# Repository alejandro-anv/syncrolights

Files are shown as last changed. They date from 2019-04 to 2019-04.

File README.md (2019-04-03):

# syncrolights

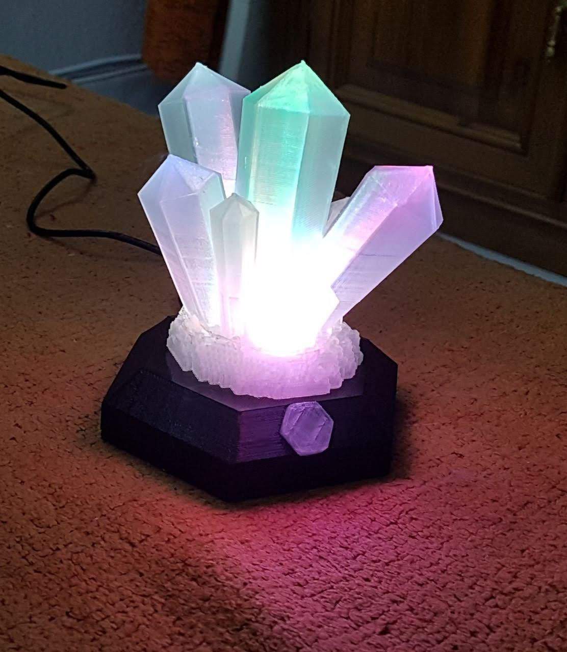
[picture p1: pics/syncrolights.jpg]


This project consists on a system of decorative lights that changes color by pressing a button, but syncronyzed through internet with their "partners". So, when the color of one of them is changed, the others mimics this change.

[YouTube](https://youtu.be/mCSxQj67VzU)

# Synchronization method
For mantaning the syncronization without NAT problems, it is needed to have a central server in "the cloud". For avoiding the need of creating a server there is the alternative of using an existing public service like Telegram. I choosen to use the old IRC protocol. 

The strategy consists on that all the lights that are in the same group will keep connected to the same IRC channel. When one user changed the color, the device will send a "topic" change to the IRC channel. This way the IRC sever will notify the topic change to all the other clients that has joint this channel and then will change the color.

# Plastic parts
The case for this project consists on two parts. One of them is a simulation of crystals that I've found at thingiverse:

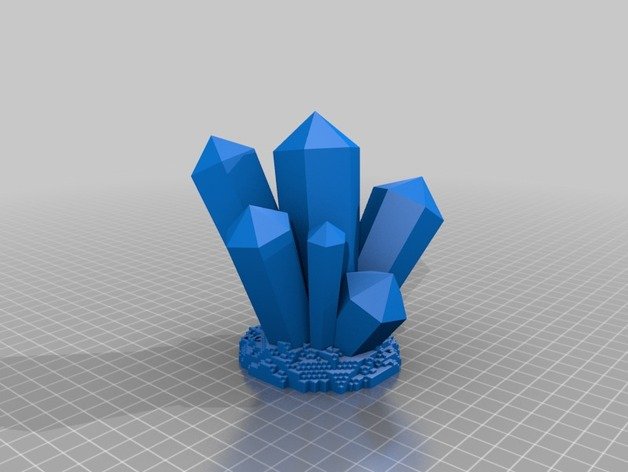
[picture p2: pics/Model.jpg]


(https://www.thingiverse.com/thing:1330791)

This crylsals will be 3D printed with tarnspartent PLA wich will result in a translulcid material and the layers will difuse the light with a prety result.

The base is printed with black PLA. I've uploaded the model to thingiverse

(https://www.thingiverse.com/thing:3537644)

# The electronics
For this function we will use a WEMOS D1 Mini module which consists on an ESP8266 processor with an USB-SRIAL CH340; they are very cehap (about $3). The color lights will be RGB LEDs driven by transistors for allowing to connect various of them without overloading the ESP9266 GPIO aoutputs. The power will be provided driectly from USB using a phone charger connected to the micro-USB port of the board.

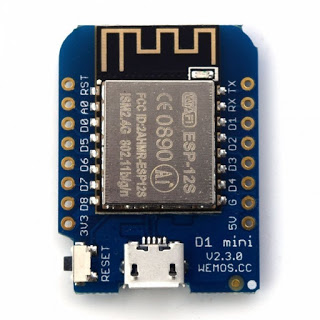
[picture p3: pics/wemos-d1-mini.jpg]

(https://www.aliexpress.com/item/D1-mini-Mini-NodeMcu-4M-bytes-Lua-WIFI-Internet-of-Things-development-board-based-ESP8266-by/32651747570.html)

For choosing the color, wee need a pushbutton. In the prototype I used a common one connected from pin D3 to GND but in the final version I decded to use some more "geek". I've found the TTP223 caacitive modules at 10 for $1,24, then I decided to include one. NOTE: for simulating the active-low effect you must solder the jumper A on the board

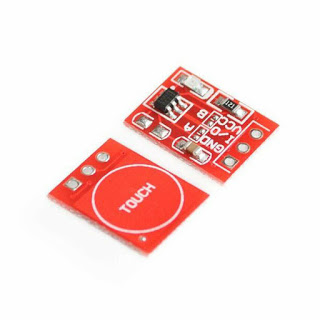
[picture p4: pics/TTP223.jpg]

https://www.ebay.com/itm/10X-TTP223-Touch-Key-Module-Capacitive-Settable-Self-lock-No-lock-Switch-Board/332931518377

Nevertheless, I've used a pushbutton that can be accessed through a small hole in the down side that will be used to enter configuration mode.
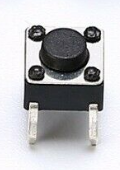
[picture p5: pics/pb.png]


(to be continued)

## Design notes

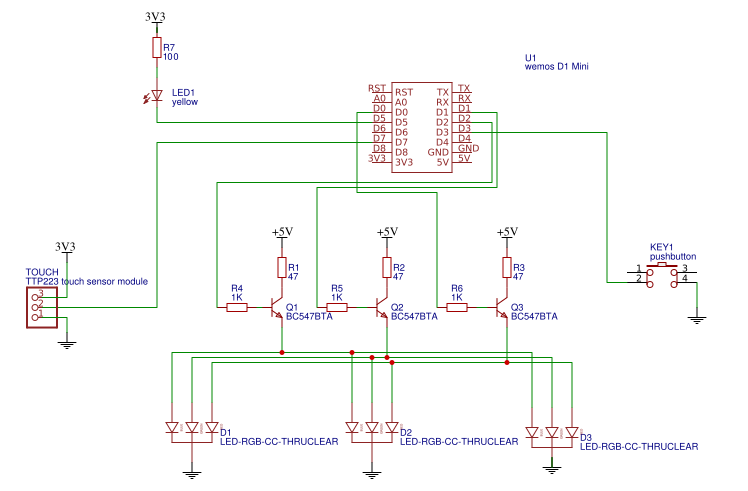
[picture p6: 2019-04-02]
Schematic.png

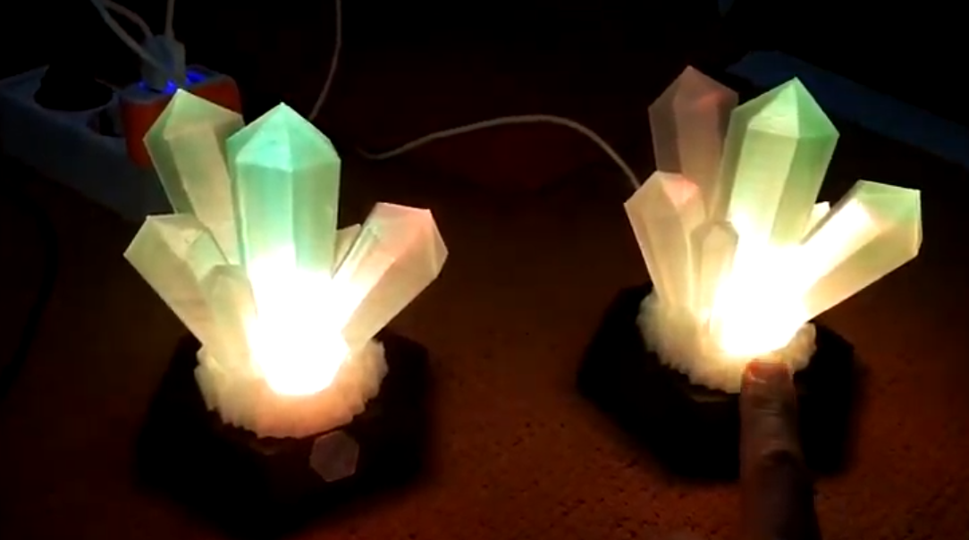
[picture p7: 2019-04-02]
pics/sl2.png

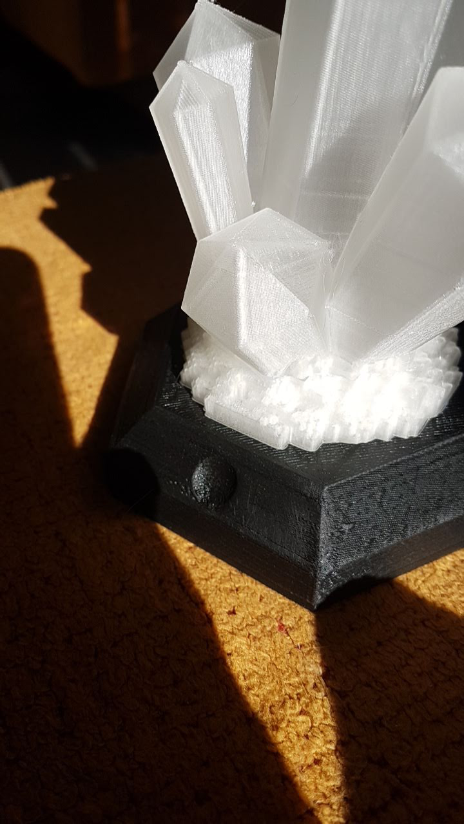
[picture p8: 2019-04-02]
pics/capacitive button.jpg

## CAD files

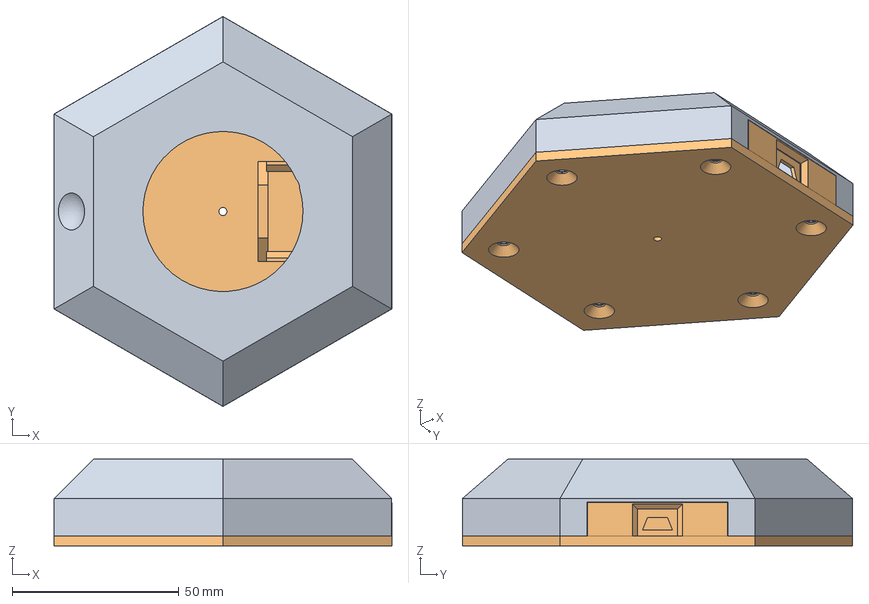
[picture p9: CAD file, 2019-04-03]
3d/sycrolights_base.fcstd
101.4 x 117.0 x 26.0 mm
superior final
inferior final

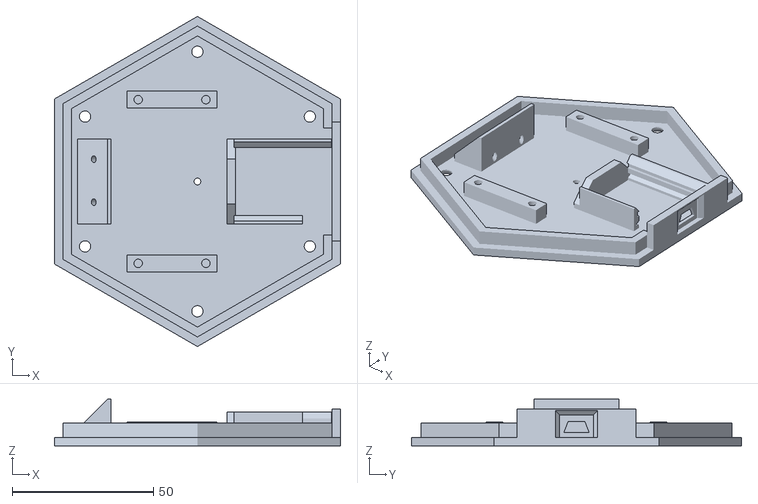
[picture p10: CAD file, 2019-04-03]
3d/down part.stl
101.4 x 117.0 x 16.5

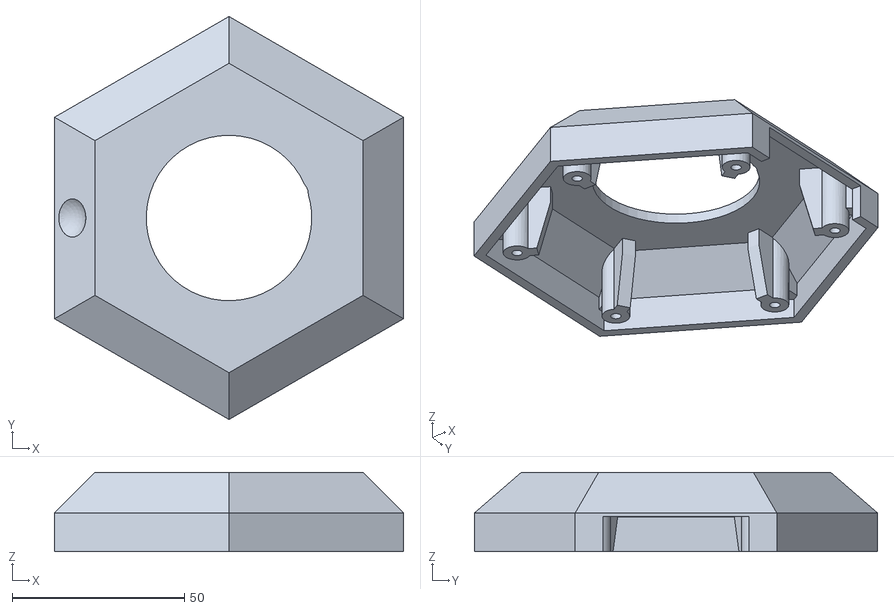
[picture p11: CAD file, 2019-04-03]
3d/up part.stl
101.3 x 116.9 x 23.0

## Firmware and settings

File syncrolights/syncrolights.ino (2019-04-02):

/******************************************************************************
    Copyright (C) 2019 by Alejandro Vargas <alejandro.anv@gmail.com>

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
    You should have received a copy of the GNU General Public License
    along with this program.  If not, see <http://www.gnu.org/licenses/>.
******************************************************************************/

// docs at https://github.com/iotappstory/ESP-Library

#define MODE_BUTTON_SHORT_PRESS       500
#define MODE_BUTTON_LONG_PRESS        4000
#define MODE_BUTTON_VERY_LONG_PRESS   10000
#define CALLHOME_INTERVAL 60

#define PING_TIME 1000*60
#define MSG_TIME 1000*600
#define TOPIC_TIME 1000*2

#define DEBOUNCEDELAY 50


#define LEDR D0
#define LEDG D1
#define LEDB D2



#define COMPDATE __DATE__ __TIME__
#define MODEBUTTON 0                                        // Button pin on the esp for selecting modes. D3 for the Wemos!

#define CHANNEL_PREFIX "#anvEsp8266"


#include "Arduino.h"
#include "uCRC16Lib.h"
#include <Ticker.h>  //Ticker Library

#include <IOTAppStory.h>                                    // IotAppStory.com library
IOTAppStory IAS(COMPDATE, MODEBUTTON);                      // Initialize IOTAppStory

Ticker anvticker;

String grupo=""; 
String devicename=""; 


String channel;
String nick="Ep";

const byte interruptPin = 13;
#define LED1 D5



const char* host = "chat.freenode.net";
int estado_actual=0;
byte color=0;

unsigned long lastDebounceTime = 0;



String ultima_linea="";
String topic="";

bool hola=1;

WiFiClient client;

char* yourname="test device";
char* groupname="test";

/////////////////////////////////////////////////////////
void blinkled(){
  digitalWrite(LED1, !(digitalRead(LED1)));  //Invert Current State of LED  
}

// ================================================ SETUP ================================================
void setup() {
  pinMode(LED1, OUTPUT);
  anvticker.attach(0.1, blinkled);
   
  IAS.preSetDeviceName("syncrolights");                         // preset deviceName this is also your MDNS responder: http://iasblink.local

  memchr(groupname,0,sizeof(groupname));
  
//  IAS.addField(LEDpin, "ledpin", 2, 'P');                   // These fields are added to the config wifimanager and saved to eeprom. Updated values are returned to the original variable.
//  IAS.addField(blinkTime, "Blinktime(mS)", 5, 'N');         // reference to org variable | field label value | max char return

  IAS.addField(yourname, "YOUR NAME", 64, 'L');
  IAS.addField(groupname, "GROUP NAME", 64, 'L');


  // You can configure callback functions that can give feedback to the app user about the current state of the application.
  // In this example we use serial print to demonstrate the call backs. But you could use leds etc.
  IAS.onModeButtonShortPress([]() {
    Serial.println(F(" If mode button is released, I will enter in firmware update mode."));
    Serial.println(F("*-------------------------------------------------------------------------*"));
  });

  IAS.onModeButtonLongPress([]() {
    digitalWrite(LED1,HIGH);
    Serial.println(F(" If mode button is released, I will enter in configuration mode."));
    Serial.println(F("*-------------------------------------------------------------------------*"));
  });

  IAS.onConfigMode([]() {
    digitalWrite(LED1,HIGH);
    Serial.println(F(" Entering config mode."));
    Serial.println(F("*-------------------------------------------------------------------------*"));
  });

  IAS.onFirmwareUpdateDownload([]() {
    digitalWrite(LED1,HIGH);
    Serial.println(F("*-------------------------------------------------------------------------*"));
    Serial.println(F(" Downloading update."));
  });


  
   IAS.begin('P');                                           // Optional parameter: What to do with EEPROM on First boot of the app? 'F' Fully erase | 'P' Partial erase(default) | 'L' Leave intact

  //IAS.setCallHome(true);                                    // Set to true to enable calling home frequently (disabled by default)
  //IAS.setCallHomeInterval(CALLHOME_INTERVAL);               // Call home interval in seconds, use 60s only for development. Please change it to at least 2 hours in production
	
  //-------- Your Setup starts from here ---------------

  pinMode(LEDR, OUTPUT);
  pinMode(LEDG, OUTPUT);
  pinMode(LEDB, OUTPUT);
  digitalWrite(LEDR,LOW);
  digitalWrite(LEDG,LOW);
  digitalWrite(LEDB,LOW);

  anvticker.detach();
  digitalWrite(LED1,LOW);
  

  unsigned char mac[6];
  WiFi.macAddress(mac);
  
  for (int i = 3; i < 6; ++i) 
      nick += String(mac[i], 16);


  devicename=String(yourname);

  if (groupname=="") grupo="test";
  else grupo=String(groupname);
  
  char buf[5];
  uint16_t crc=calccrc(CHANNEL_PREFIX+grupo);
  sprintf(buf,"%04x",crc);
  
  channel=CHANNEL_PREFIX+String(buf);
 
  pinMode(interruptPin, INPUT_PULLUP);
  attachInterrupt(digitalPinToInterrupt(interruptPin), handleInterrupt, FALLING);

  digitalWrite(LED1,LOW);
   
  Serial.println("=====================================================================================================");
  Serial.println("WiFi connected");  
  Serial.println("IP address: ");
  Serial.println(WiFi.localIP());
  Serial.println("nick: "+nick);
  Serial.println("channel: "+channel);
  Serial.println("=====================================================================================================");

}






byte errores=0;
///////////////////////////////////////////////////////////////////////////////
bool conectar_irc(){

anvticker.attach(0.3, blinkled);

Serial.println("iniciando conexion...");
client.stop();
delay(500);
if (!client.connect(host, 6667)) {
   Serial.println("No se pudo abir socket");
   errores++;
   //if (errores>20) 
   if (errores>20) {
       //ESP.restart();
       //ESP.reset();
       WiFi.forceSleepBegin(); wdt_reset(); ESP.restart(); while(1)wdt_reset();
       }
        
   return false;
   }  
errores=0;

    
Serial.println("Conectado, iniciando sesion.");

delay(1000);
while(client.available()) {
  char c = client.read();
  Serial.print(c);
  }



String extranick="";
int n=0;
byte r;
do {
   Serial.println("enviando nick "+nick+extranick);

   client.print("NICK "+nick+extranick+"\n");
   client.print("USER "+nick+extranick+" 8 * :"+nick+extranick+"\n");
   
   r=esperar_respuesta("Welcome","already in use",30);
   if (r==2) {
      n++;
      extranick=String(n,16);
      }
   } while (r==2);

if (r!=1) {
   Serial.println("Error al enviar nick");
   return false;
   }


Serial.println("enviando join a "+channel);
client.print("JOIN "+channel+"\r");
r=esperar_respuesta("JOIN "+channel,"",30);

Serial.println("Esperando '332 "+nick+extranick+" "+channel+" :' para obtener el topic");
r=esperar_respuesta("332 "+nick+extranick+" "+channel+" :","",10);
//if (r==1) 
procesar_topic(0);

hola=1;
digitalWrite(LED1,LOW);
anvticker.detach();  
}

unsigned long PingPreviousMillis = 0;
unsigned long MsgPreviousMillis = 0;
unsigned long TopicPreviousMillis = 0;

///////////////////////////////////////////////////////////////////////////////
bool verificar_conectado(){
if (WiFi.status() != WL_CONNECTED) {
   Serial.println("no hay conexion wifi");
   return false;
   }

if (!client.connected()) {
    return conectar_irc();
    }

unsigned long PingCurrentMillis = millis();
if (PingCurrentMillis - PingPreviousMillis >= PING_TIME) {  
    PingPreviousMillis = PingCurrentMillis;
    if (! verificar_ping()) return conectar_irc();
    }

return true;
}

//////////////////////////////////////////////////////////////////////////////
bool verificar_ping(){

String mensaje="ANV";
unsigned char mac[6];
WiFi.macAddress(mac);

for (int i = 0; i < 6; ++i) 
   mensaje += String(mac[i], 16);

Serial.println("enviando PING "+mensaje);

client.print("PING "+mensaje+"\n");

if (esperar_respuesta(mensaje,"",5)==1) {
  Serial.println("recibida respuesta a ping");
  return true;
  }

Serial.println("No se recibe respuesta al ping\n");    
return false;
}
/////////////////////////////////////////////////////////////////////////////
byte esperar_respuesta(String texto1,String texto2,unsigned int tiempo){
client.setTimeout(100);

for (int i=0;i<tiempo*10;i++){
    ultima_linea=client.readStringUntil('\r');
    if (ultima_linea.length()>0) Serial.println(ultima_linea);
    
    if (texto1.length()>0 && ultima_linea.indexOf(texto1)>0) return 1;
    if (texto2.length()>0 && ultima_linea.indexOf(texto2)>0) return 2;
    }
Serial.println("No se ha recibido ni '"+texto1+"' ni '"+texto2+"'");    
return 0;  
}

//////////////////////////////////////////////////////////////////////////////
bool cambiar_topic(String t){

uint16_t crc;
char buf[5];
crc=calccrc(t+grupo);
sprintf(buf,"%04x",crc);
  
client.println("TOPIC "+channel+" :"+String(buf)+t);

//return (esperar_respuesta("TOPIC "+channel+" :"+t,"",10)==1);

}




//////////////////////////////////////////////////////////////////////////////////////////


unsigned int hexToDec(String hexString) {
  
  unsigned int decValue = 0;
  int nextInt;
  
  for (int i = 0; i < hexString.length(); i++) {
    
    nextInt = int(hexString.charAt(i));
    if (nextInt >= 48 && nextInt <= 57) nextInt = map(nextInt, 48, 57, 0, 9);
    if (nextInt >= 65 && nextInt <= 70) nextInt = map(nextInt, 65, 70, 10, 15);
    if (nextInt >= 97 && nextInt <= 102) nextInt = map(nextInt, 97, 102, 10, 15);
    nextInt = constrain(nextInt, 0, 15);
    
    decValue = (decValue * 16) + nextInt;
  }
  
  return decValue;
}
/////////////////////////////////////////////////////////////////////////////////////////

uint16_t calccrc(String s){
char buf[256];
uint16_t crc;

s.toCharArray(buf,sizeof(buf));

crc=uCRC16Lib::calculate(buf, strlen(buf));
return crc;
}

///////////////////////////////////////////////////////////////////////
void procesar_topic(byte b){    
uint16_t crc_recibido;
uint16_t crc_calculado;

String tmp;
int p;

String buscar;

if (b==1) 
  buscar="TOPIC "+channel+" :";
else 
  buscar=channel+" :";


p=ultima_linea.indexOf(buscar);

if (p<1) {
  if (b==0) {
     Serial.println("no se encuentra cadena de topic en >>>"+ultima_linea+"<<<<");
     Serial.print("Parece que el canal no tiene topic");
     cambiar_topic(String(estado_actual));
     Serial.println("Asignando "+String(estado_actual));
     }
  return;
  }

    
Serial.println("Cambio de topic del canal a '"+ultima_linea.substring(p+buscar.length())+"'");
//topic=ultima_linea.substring(p+buscar.length());



tmp=ultima_linea.substring(p+buscar.length()+4);

crc_recibido=hexToDec(ultima_linea.substring(p+buscar.length(),p+buscar.length()+4));
crc_calculado=calccrc(tmp+grupo);


Serial.print("ultima_linea="); Serial.println(ultima_linea);
Serial.print("buscar="); Serial.println(buscar);
Serial.print("p="); Serial.println(p);
Serial.print("cadena del crc="); Serial.println(ultima_linea.substring(p+buscar.length(),p+buscar.length()+4));
Serial.print("tmp="); Serial.println(tmp);
Serial.println(crc_recibido,HEX);
Serial.print("crc calculado=");
Serial.println(crc_calculado,HEX);




if (crc_recibido==crc_calculado){

   topic=tmp;
   estado_actual=topic.toInt();
   Serial.println("NUEVO TOPIC="+topic);
   color=estado_actual;
   showcolor();
   }
else {
   
   Serial.print("El topic no es valido: \ncrc recibido=");
   Serial.println(crc_recibido,HEX);
   Serial.print("crc calculado=");
   Serial.println(crc_calculado,HEX);
   cambiar_topic(String(estado_actual));
   Serial.println("Asignando "+String(estado_actual));
   }
}

///////////////////////////////////////////////////////////////////////////////////////////////////////////
void showcolor(){
digitalWrite(LEDR,(color & 1));
digitalWrite(LEDG,(color & 2)>>1);
digitalWrite(LEDB,(color & 4)>>2);
  
}
///////////////////////////////////////////////////////////////////////////////////////////////////////////
void handleInterrupt() {

if ((millis() - lastDebounceTime)<DEBOUNCEDELAY) return;
  
lastDebounceTime = millis();
color++;
if (color>8) color=0;

showcolor();  
}

// ================================================ LOOP =================================================
void loop() {
  IAS.loop();                                // this routine handles the calling home on the configured itnerval as well as reaction of the Flash button. If short press: update of skethc, long press: Configuration


  //-------- Your Sketch starts from here ---------------

int p;

verificar_conectado();  
client.setTimeout(100);

if (client.available()){
  ultima_linea=client.readStringUntil('\r');

  Serial.println(ultima_linea);
  procesar_topic(1);    
  }

unsigned long TopicCurrentMillis = millis();
if (estado_actual!=color && TopicCurrentMillis - TopicPreviousMillis >= TOPIC_TIME) {  
    TopicPreviousMillis = TopicCurrentMillis;
    Serial.println("Color changed, sending topic change\n");
    cambiar_topic(String(color));
    }


unsigned long MsgCurrentMillis = millis();
if (hola || MsgCurrentMillis - MsgPreviousMillis >= MSG_TIME) {  
    MsgPreviousMillis = MsgCurrentMillis;
    client.print("PRIVMSG "+channel+" : "+devicename+" ");
    client.print(WiFi.localIP());
    client.print("\r");
    hola=0;
    }

   
//TODO:
// <-PING :asimov.freenode.net
// ->????????????????


}

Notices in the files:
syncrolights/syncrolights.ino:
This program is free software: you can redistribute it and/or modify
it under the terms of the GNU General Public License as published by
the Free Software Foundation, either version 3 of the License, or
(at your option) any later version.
